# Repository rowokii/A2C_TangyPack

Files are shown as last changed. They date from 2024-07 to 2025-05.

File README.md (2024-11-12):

# A2C_TangyPack
Allows VGA and HDMI (DVI) video device to be connected to Apple IIc/IIc+ (US NTSC Machine only). 

[Laser 128 support](Laser128.md) added with Firmware V1.10

If you want to purchase one, it's avaiable from ct6502.org: [https://ct6502.org/product/tangypack/](https://ct6502.org/product/tangypack/)
</br>Please read the following [document](Compatibility.md) on compatibility before ordering. 

### WARNING!!!  Do not plug/unplug the device to/from the Apple IIc with the power on.  Damage to the device and/or to your Apple IIc can occur.  It is strongly recommended to lock the screw terminal down to prevent the device from being accidentally disconnected. 

* HDMI specification allows for hot plugging the connector.  
* Hot plugging VGA connector is not defined in the specification and there is mixed information regarding if it is safe.

# Descrpition
A2C_TangyPack plugs into the video expansion port of the Apple IIc/IIc+ and is powered from the port itself.  It is a scan doubling device that will take the 560x192 video of the Apple IIc and upscale the video to ~640x480 (720x480 @ 28.63MHz pixel rate) video resolution supported by most modern video monitors. 

## Compatibility
This became a larger topic that deserves a separate [document](Compatibility.md).   Please completely read through the document before you decide if the Tangy Pack will work for your and ordering the device

## Controls
Controls are simple.  Push the corresponding buttons to cycle through the options listed. Power on defaults are the first options of each row.  
  
  A - Toggles scanline effect On/Off  
  B - Color mode, Mono Green, Mono Amber, Mono White  
  C - Border off, Border White, Border Blue, Border Green  
  
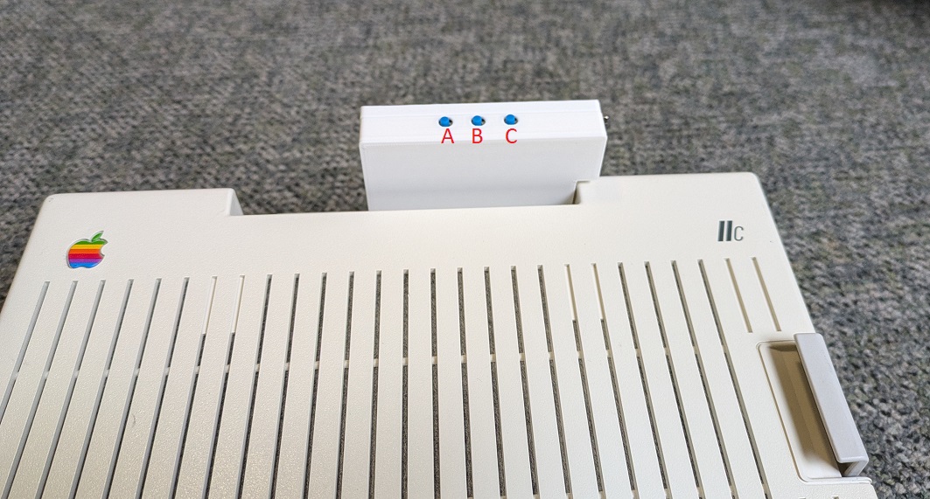
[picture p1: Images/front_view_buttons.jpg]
Front_View


# Firmware
Please read the following for the [Firmware Update](./Firmware/Firmware.md) procedure.
<br/>Firmware release notes are [here](./Firmware/Firmware_Releases.md). 

# Case STL files
If you want to print your own case, the .stl files are available in the Case STL directory.  <br/>See the [Case_STL_readme](./Case%20STL/Case_STL_readme.md) for more information.

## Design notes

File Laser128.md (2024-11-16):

# Laser 128 Support
TangyPack now works (using Firmware V1.10) on the Laser 128, with a few caveats.    <br/>Tangy Pack will auto detect when plugged into the Laser 128.

* **The original case that shipped with the Tangy Pack will not fit on the Laser 128.  Laser 128 compatible case stl is available in the Case STL folder if you have a 3D printer and you want to print your own.  Tangy Pack purchased on/after November 2024 will come with the Laser 128 compatible case**
* The case and firmware was tested with the newer style Laser 128 with  Rom V4.3 and V6.0 <br/> I do not have the old style laser 128, Laser 128EX or EX/2 so untested on these machine.  If you have these machine and the Tangy Pack works on it, please drop me a note.
* Laser 128 must have the MONO/COLOR switch in MONO setting. (Tangy Pack will display color images)
* Tangy Pack is not using the RGB signals on the Laser 128. It is using the digital serial output data and displaying the image in same way it does with the Apple IIc.  
* Laser 128 is missing the GR signal available on the Apple IIc that is used to kill the color on text modes.  This means, the Laser 128 display will always display in color unless you change the mode on the Tangy Pack itself using the "B" button.
* CREF (color reference) signal available on the Apple IIc is missing from the Laser 128.  I am internally generating the color reference from the sync video signal. Unfortunately, the color reference has different timing relationship in double high res mode and I can not detect this. <br/> So, button "A", when in Laser 128 mode, allows you to manually change the internal CREF state.  There are four valid CREF state. Each press of the button A changes the mode in the following order.
  * CREF state A - Scan line on (Default)
  * CREF state A - Scanline off
  * CREF state B - Scanline on
  * CREF state B - Scanline off
  * CREF state C - Scan line on
  * CREF state C - Scanline off
  * CREF state D - Scanline on
  * CREF state D - Scanline off
* The video timing is just a tad more out of spec compare to the Apple IIc after scan doubling.  This means some finicky monitors that work with the Tang Pack in the Apple IIc mode will not work on the Laser 128.

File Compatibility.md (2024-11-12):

# Compatibility

### A2C_TangyPack is NOT compatible with PAL at this time.

## NTSC Apple IIc/IIc+

TangyPack uses a technique called scan doubling to generate it's video signals for the VGA and HDMI/DVI compatible output.  This is method is relatively simple to implement and has minimal delay on the output image, but is tightly coupled to the source video signal timing.  Scan doubling the Apple IIc video output gets us fairly close to the 640x480 @ 60Hz video standard, but is technically out of spec.  

 **This means while many video displays will work with it, some will not.**   

 Here is a list of devices I have tested or have been reported by others to either work or not work with the Tangy Pack. [Tangy Pack Compatibility List](./Tangy%20Pack%20Compatibilty%20List%20.ods)

Please be aware some displays will scale and apply image filtering to the input images which will destroy the scanline effects and/or stretch the image from it's normal 4:3 size.

In addition, the HDMI port implementation of the Tang Nano 9K FPGA board is not strictly speaking, compliant to the HDMI/DVI standard.  This can causes several problems, which we will cover in the below section.

## Desktop Computer Monitors 
In general, these devices have the best compatibility with the HDMI/DVI and VGA outputs.  Also in general, the VGA input has better compatibility than the HDMI input.  I have a small "Security Monitor LCD" and a late 2000 LCD TV monitor that has both VGA and HDMI input.  Both LCDs works fine on the VGA input, but the HDMI input will show either blank screen or "Resolution not supported" message.

## TVs with HDCP 

These devices usually requires CEC, SCL and SDA signals on the HDMI connector to be pulled up to 5V through pull up resistors.

Tang Nano 9K does have the pull up resistors, but the 5V is not connected on the board.  

A simple $10 device called "USB Power Inserter" like this one https://www.amazon.com/dp/B08MFG27XM?ref=ppx_yo2ov_dt_b_fed_asin_title  supplies the 5V on the connector.  My LG and Samsung LCD TVs works fine with the Tangy Pack using this device. 

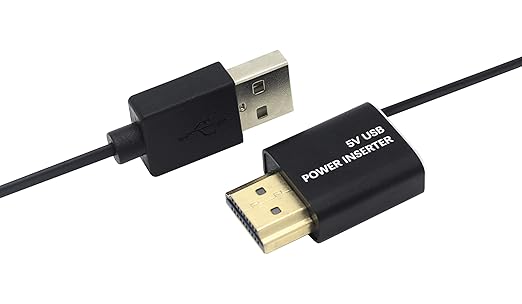
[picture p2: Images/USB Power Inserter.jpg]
Power Inserter Image
 

## HDMI Capture Cards

Tang Nano does not have the HPD(Hot Plug Detect) pin connected.  This seems to confuse the capture cards when you plug in the HDMI connector with the capture card powered up and active.  Having everything connected and then plugging in the capture card and then activating the device seems to work best for me.

Second issue is that some of the capture cards seems to be very particular about the video timing or does not support the 640x480@60 resolution.  One capture device I have will not lock to even to spec compliant 640x480@60 test signal.  

Third issue seems to be some of these devices does not like the output driver of the Tang Nano.  It causes image artifacts on the screen like shown below.

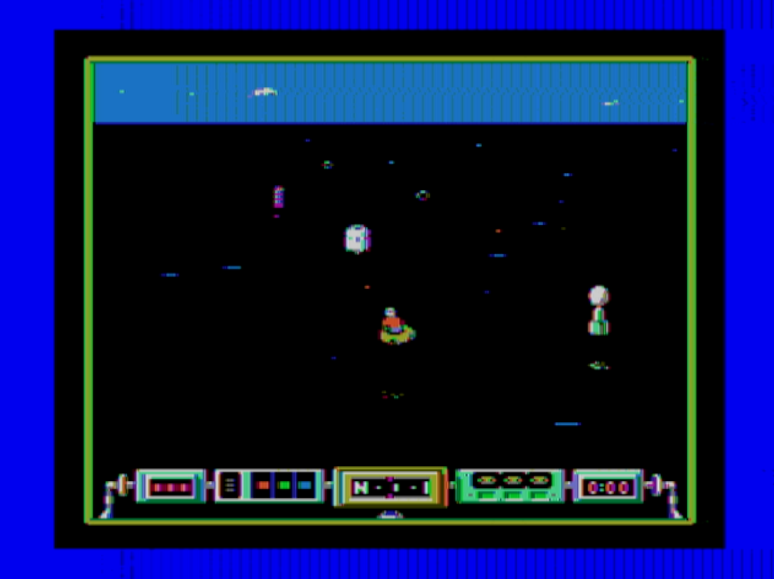
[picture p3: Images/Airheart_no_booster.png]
distorted image


Using an active HDMI signal repeater/booster device fixes the image problem. 

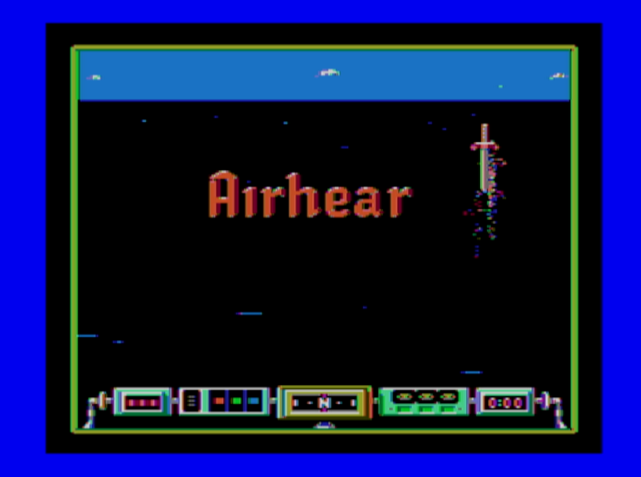
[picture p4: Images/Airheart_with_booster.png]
clean image


What you are looking for is an **active** hdmi repeater. The passive HDMI connector meant to just extend the cable will not work.  Amazon seems to have a few models from ~$20 to ~$40.  I also found a few ~$10 devices on Aliexpress that seems to work.  Here's the list of devices that I have tried.

* [Amazon Bytecc HDMI Amplifier Repeater ](https://www.amazon.com/dp/B0CRK292K6?ref=ppx_yo2ov_dt_b_fed_asin_title&th=1) ~$25 Worked
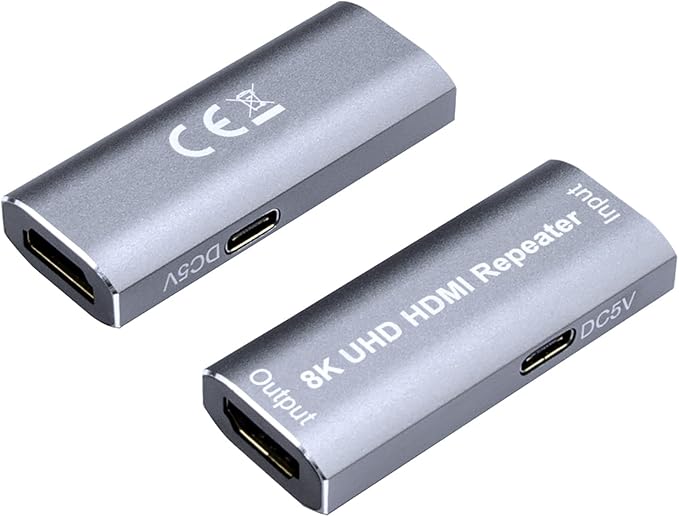
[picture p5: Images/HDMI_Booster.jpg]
HDMI Booster
<br/>
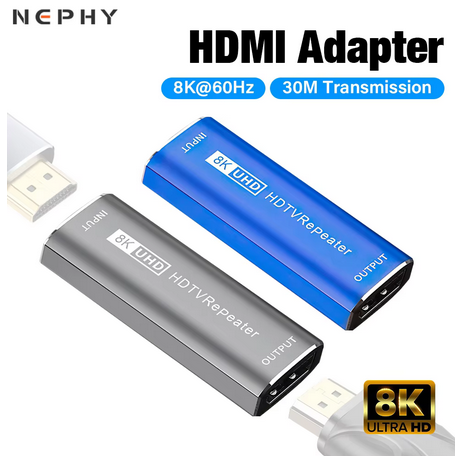
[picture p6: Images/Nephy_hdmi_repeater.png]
NEPHY Image
* [Aliexpress - 8K HDMI Signal Amplifier Booster Extender](https://www.aliexpress.us/item/3256806506866287.html) ~$8 Worked <br/>

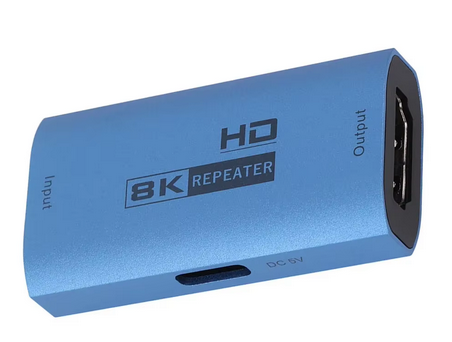
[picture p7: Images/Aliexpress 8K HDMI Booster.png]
Ali HDMI Booster
* [Aliexpress - 8K Extender Repeater](https://www.aliexpress.us/item/3256806639053743.html) ~$8 Worked <br/>
* [Aliexpress - Mini 4K*2K HDMI 2.0 Extender](https://www.aliexpress.us/item/3256804417878705.html) ~$15.  **Did NOT work** . Looses lock and blinks
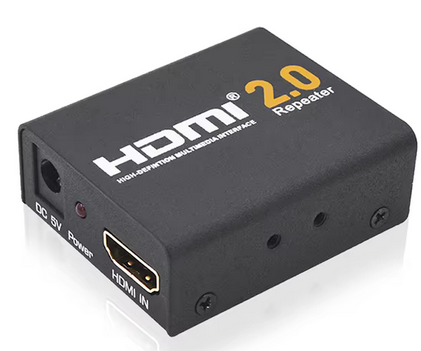
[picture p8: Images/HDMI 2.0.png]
HDMI 2.0 Booster
<br/>

Using the active HDMI booster, I was able to get two (Grey and larger black) of my test capture devices to work.  I could not get the small black HDMI to USB2 capture device to work at all.

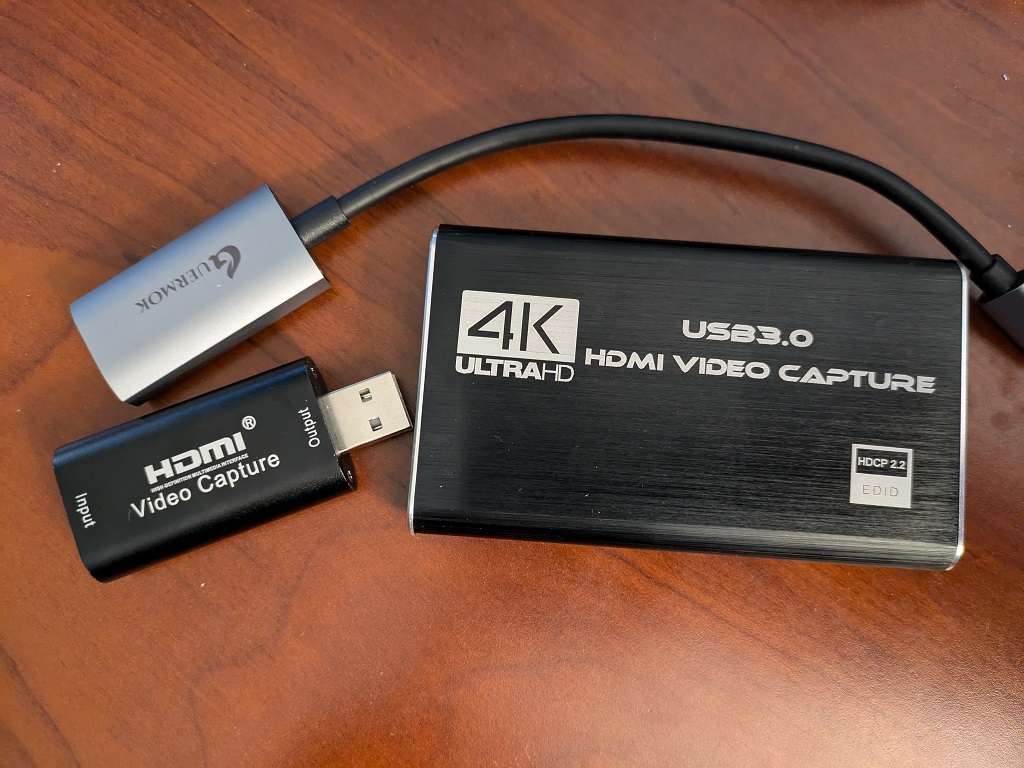
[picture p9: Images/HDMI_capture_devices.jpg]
HDMI Capture Devices


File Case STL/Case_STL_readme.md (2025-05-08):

The files for the case of the Tangy Pack is in this folder.  

The case has been designed and tested to print in ABS, but as long as you print both the front and back of the case in same material, it should be OK to print in PLA or PETG.  

PLA might be too brittle for Clips.stl so you should print it in PETG or ABS. 

Additional hardware:
  - 5 - "Voron" style heat inserts.  M3 x 5 x 4 (M3 thread, OD 5mm, length 4mm).  
  - 5 - M3 x 8mm flat head phillips head.

Print Settings used:
  - Polymaker ABS, White (Some early cases printed in Bambulab ABS, white)
  - 0.4mm Nozzle
  - 0.2mm layer
  - 0.4mm line width
  - 4 walls, 5 top and bottom layers
  - 25% Adaptive Cubic infill
  - No support needed (front case has built in support)
  - Brim is recommended for ABS (not needed for the clips.stl)

Print Files
  - Tangy_Pack_back.stl - Back of the case
  - Tangy_Pack_front_support_V2.stl - Updated case front that is compatible with Apple IIc and Laser 128.  It has built in support
  - clip.stl -clip used to hold in the tab screws

  Alternative
  - Tangy_Pack_front_support.stl - Front of the case with built in support (original Apple IIc only case)
  - Tangy_Pack_front_NO_support.stl - This is the front of the case without built in support if you want to use your own support, modify the design or use different print orientation
  - Tangy_Pack_front_NO_support_V2.stl - V2 case without support.

Extra 
  - TN9K_PCB_spacer.stl - Only used as spacer jig when assembling the PCB.

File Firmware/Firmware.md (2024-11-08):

# Firmware Update Procedure

## Taking apart the Tangy Pack

Remove the 5 M3x8mm screws using a phillips #1 screw driver from the back of the Tang Pack.  Lift off the back, including the locking screws.  

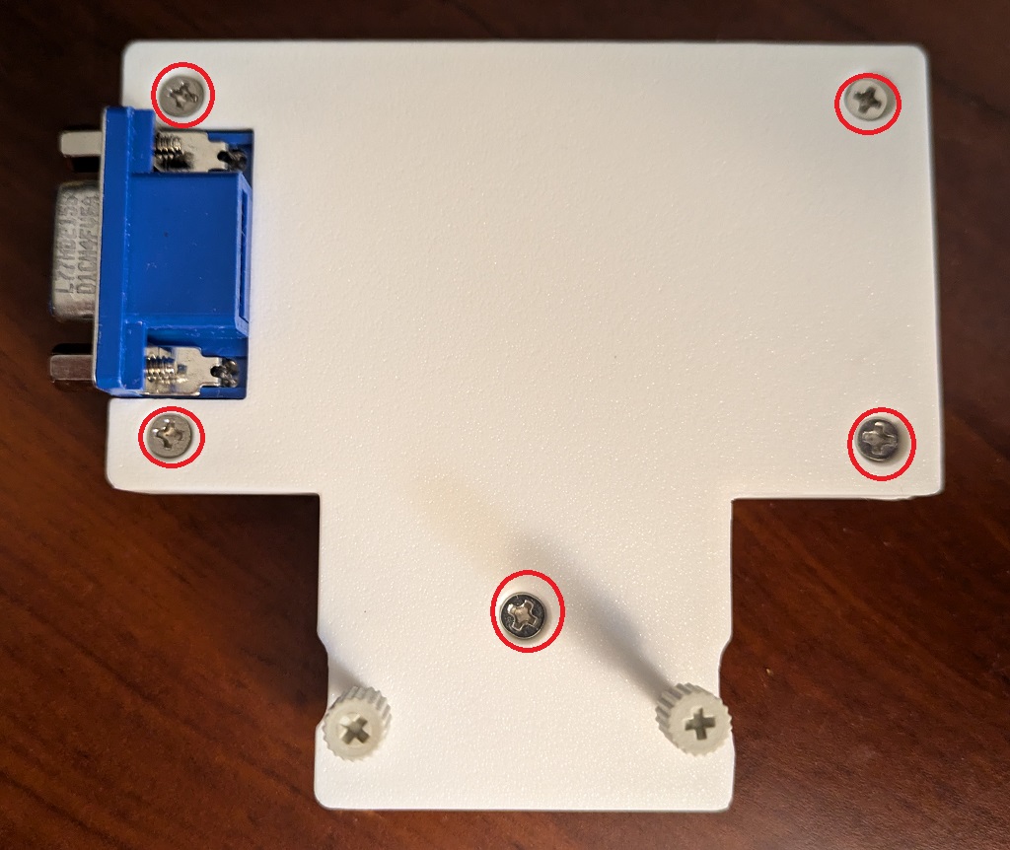
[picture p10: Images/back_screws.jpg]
Back_Screws


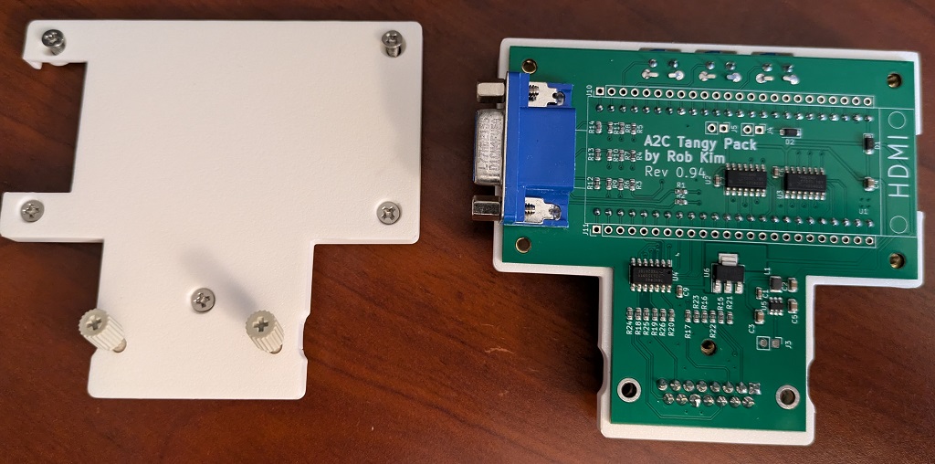
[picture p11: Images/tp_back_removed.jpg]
tp_back_removed


Once the back is removed, remove the PCB from the front case and flip it over.  There is a USB C connector under the SD card slot.  

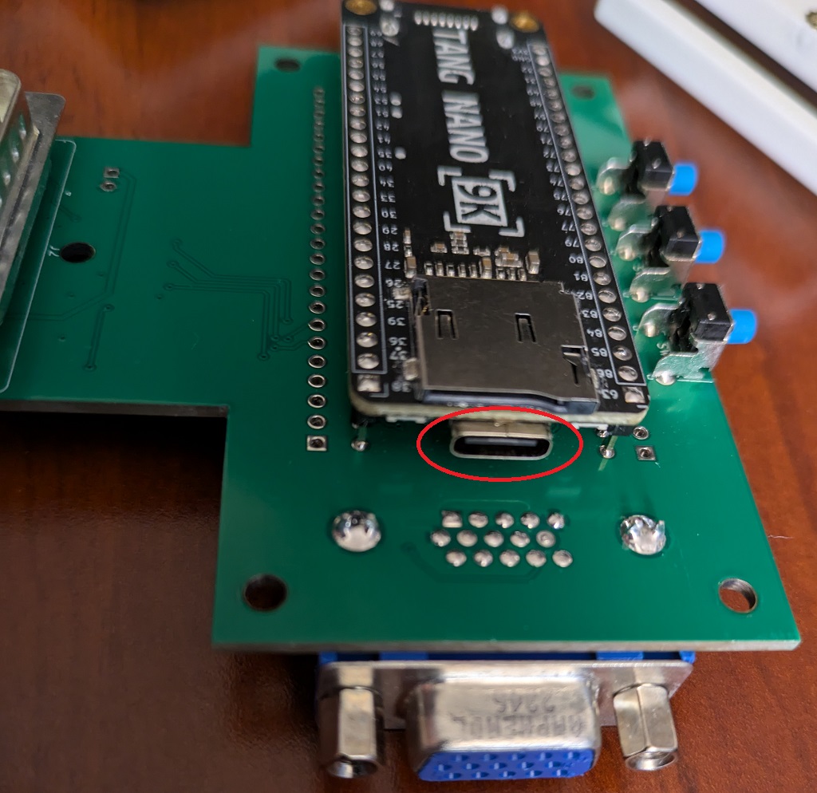
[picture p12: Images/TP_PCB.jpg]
TP_PCB


# Uploading the firmware

Once you have access to the USB C connector on the Tangy Pack, you have two options to upload the firmware file (Firmware_Name.fs).  Option 1, I feel is easier if you just want to upload the firmware.  Use option 2 if you want to get into development with Tang Nano FPGAs.

## Option 1: openFPGALoader

[openFPGALoader](https://github.com/trabucayre/openFPGALoader) is a fantastic open source software that allows you to program many FPGA boards from many manufacturers.   It works under Linux, Windows and macOS.  While the [installation guide](https://trabucayre.github.io/openFPGALoader/guide/install.html) has instructions for linux and macOS, the windows section is blank.

I was able to install and use openFPGALoader under Windows using the following [guide](https://fpga.mit.edu/6205/F22/documentation/openFPGA).  It uses [MSYS2](https://www.msys2.org/) for the actual install of the tool and command shell and [Zadig](https://zadig.akeo.ie/) for driver installation.  Only difference I ran into when following the guide was when replacing the FTDIBUS driver for WinUSB, my Tang Nano 9K device was listed as "JTAG Device" instead of "Digilent USB Device".  You need to update both interface 1 and interface 2 with WinUSB.

After you have installed the openFPGALoader, copy the firmware_name.fs file to a directory accessible from your MSYS2 command window.  Connect the Tang Nano 9K board to your computer and from the MSYS2 command window, you should be able to detect the board using the following command.

```
$ openFPGAloader --detect
No cable or board specified: using direct ft2232 interface
Jtag frequency : requested 6.00MHz   -> real 6.00MHz
index 0:
        idcode 0x100481b
        manufacturer Gowin
        family GW1N
        model  GW1N(R)-9C
        irlength 8
```

Assuming the firmware file is in the correct directory, you can use the following command to upload the new firmware

```
$  openFPGAloader -b tangnano9k -f A2C_TangyPack_V1p00.fs
write to flash
Jtag frequency : requested 6.00MHz   -> real 6.00MHz
Parse file Parse A2C_TangyPack_V1p00.fs:
Done
DONE
Jtag frequency : requested 2.50MHz   -> real 2.00MHz
erase SRAM Done
erase Flash Done
write Flash: [==================================================] 100.00%
Done
```

## Option 2: Install the Gowin EDA and Programmer

Gowin is the FPGA chip manufacturer.  They have a student version of the GOWIN EDA does not require any license to run.  It has reduced device support and feature, but the FPGA used in the Tang Nano 9K is supported

Sipeed is the manufacturer of [Tang Nano 9K](https://wiki.sipeed.com/hardware/en/tang/Tang-Nano-9K/Nano-9K.html) board used in the Tangy Pack.  They have a forked version of the Gowin programming software, that you must use to program the Tang Nano.

* [GOWIN EDA - Student Edition](https://magicjellybeanfpga.github.io/mjb/software.html)
* [Sipeed Tang Programmer](https://dl.sipeed.com/shareURL/TANG/programmer)

Once the EDA software and the programmer software has been installed, start the GOWIN EDA software.  Click on the Programmer icon.

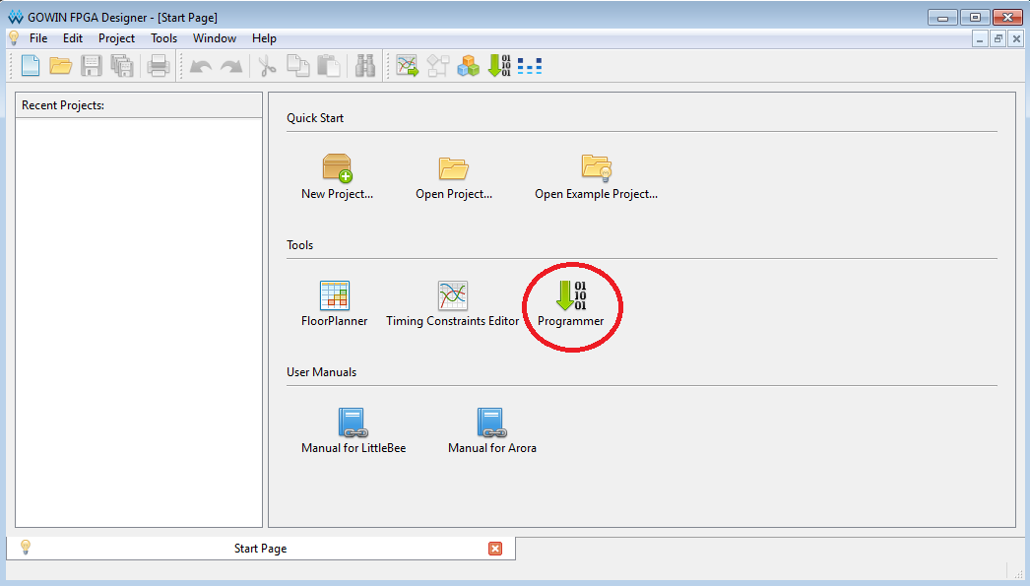
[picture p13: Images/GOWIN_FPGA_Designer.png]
GOWIN FPGA Desginer


Once the programmer software starts, connect the Tang Nano to the computer.  Click on the magnifying icon to scan for a device.  If two device shows up, select the GW1NR-9C and hit ok.

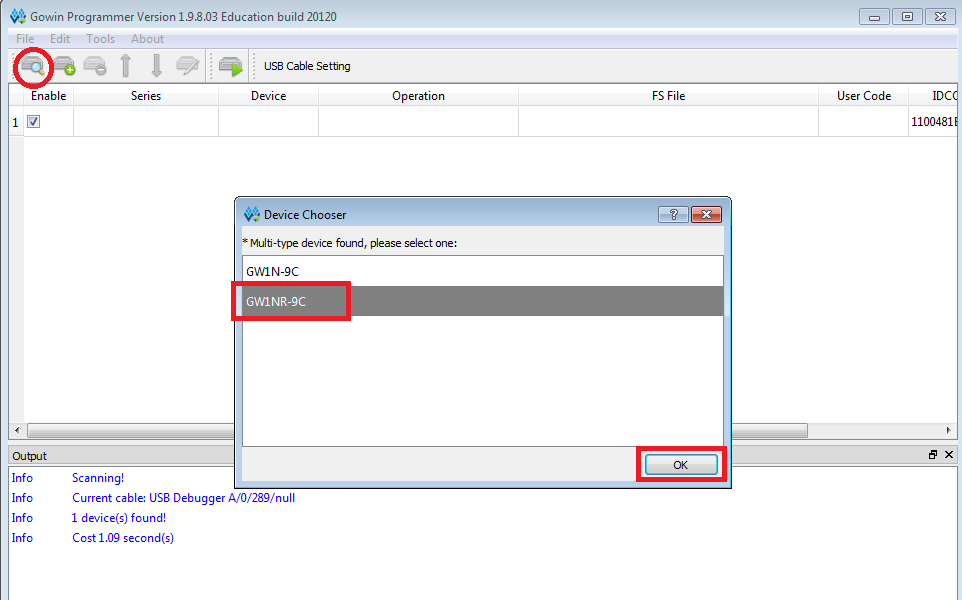
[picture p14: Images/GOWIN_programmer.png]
GOWIN Programmer


Double click on the Read Device Codes selection box.  This will bring up Device configuration window.  Select Embedded Flash Mode for Access Mode and Select embFlash Erase,Program for Operation.  

Navigate to the .fs file you want to upload for the file name and hit save

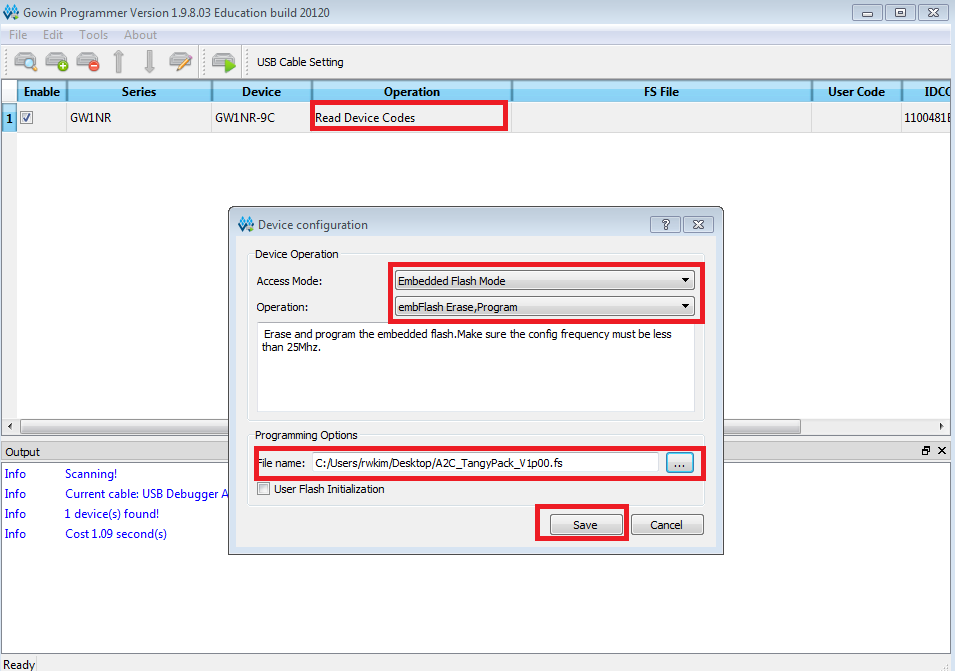
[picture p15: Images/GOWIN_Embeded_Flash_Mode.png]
GOWIN Embeded Flash


Click on the icon with green triangle to start the programming process.
You should see "Info Finished!" when the programming completes successfully.
 
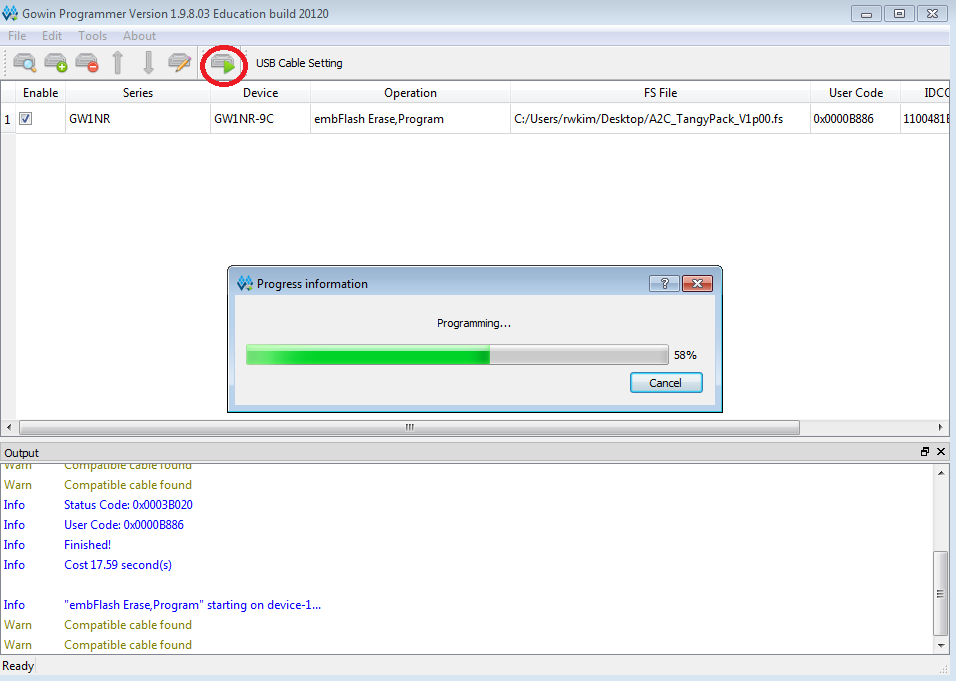
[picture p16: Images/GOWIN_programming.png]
GOWIN Programming


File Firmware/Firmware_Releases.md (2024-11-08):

# Firmware Release Notes

| Firmware Name | Description
|:---|:---|
|A2C_TangyPack_V1p00.fs | Original firmware.  Any Tangy Pack purchased before November 2024 came with this version.|
|A2C_TangPack_V1p01.fs | Fixed sync polarity on VGA output which prevented some monitors from centering the image properly.  By default, turn on the white border to help monitors that auto sync on power up.  Previously found in the Experimental section under A2C_TangyPack_V1p00_sync_invert_exp_WB.fs
|A2C_TangPack_V1p10.fs | * Laser 128 support added.  It auto-detects when plugged into Laser 128 to switch mode<br/> * Draws a thin border and displays firmware version number on lower left corner for ~10 seconds on power up.<br/> * Button response improved <br/> * The color borders are now a bit thinner with more black space around the Apple IIC/Laser 128 Images|

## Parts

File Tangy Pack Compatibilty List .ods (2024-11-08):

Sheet: Monitor
 |  |  |  | Apple IIC |  | Laser 128
Type | Make | Model | Description | HDMI | VGA | HDMI | VGA | 4/3 Mode | Comments
Monitor | Acer | EK240Y | 23.8" 1920X1080P Monitor | OK | OK | OK | OK | Yes
 | Arzopa | A1 GAMUT SLIM | 14" 1920x1080P Portable Monitor | OK | N/A | OK | N/A | Yes
 | Dell | 2007FPb | 20" 1600x1200 Monitor | OK (DVI) | OK | OK (DVI) | OK | Yes | DVI to HDMI adapter or cable needed
 | Dell | E198FPb | 19" 1280x 1024 VGA Monitor | NA | OK | NA | OK | Yes
 | Dell | S2722QC | 27" 4K HDMI Monitor | Yes | NA | ? | NA | ? | Reported working on HDMI by JL
 | EYOYO | EM14A | 14" Monitor | NO (Distorted Image) | YES | ? | ? | ? | Reported working on VGA, but distorted image on HDMI by JL
 | Haiway | SM10.1 | 10.1" 1366x768 Security Monitor | NO | OK | NO | NO | Yes | Finicky about timing. Only VGA input with Apple IIc works
 | Kenowa | HD-133 | 13.3" 1366X768 Portable Monitor | OK | NA | OK | NA | Yes
 | Sony | SDM-HS53 | 15" 1024x768 VGA Monitor | NA | OK | NA | OK | Yes

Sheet: TV
 |  |  |  | Apple IIC |  | Laser 128
Type | Make | Model | Description | HDMI | VGA | HDMI | VGA | 4/3 Mode | Comments
TV | Insignia | NS-LCD19 | 19" LCD TV | NO | Yes | NO | NO | Yes | Finicky about timing. Only VGA input with Apple IIc works
 | LG | 49LJ5500-UA | 49" LCD TV | OK (5V Required) | N/A | OK (5V Required) | N/A | Yes | Requires 5V Power Injection
 | Samsung | UN50H5203AF | 50" LCD TV | OK (5V Required) | N/A | OK (5V Required) | N/A | Yes | Requires 5V Power Injection

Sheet: Capture Devices
 |  |  |  | Apple IIC |  | Laser 128
Type | Make | Model | Description | HDMI | VGA | HDMI | VGA | 4/3 Mode | Comments
HDMI Capture | Adafruit | 4910 | USB-C to HDMI Capture Card | NO | NA | NO | NA |  | Does not lock to signal - Reported by CT
 | Audio Express | AXHDCAP | HDMI to USB 2.0 Video Capture Device | NO | NA | NO | NA |  | Does not lock, blank screen
 | Guermok | ‎GVC-HDMI-USB3-4K30 | HDMI to USB3.0(USBC) Capture Device | OK(Boost Required) | NA | OK(Boost Required) | NA | Yes | Requires Active HDMI Signal Booster.
 | Rybozen | V316B-FR | HDMI to USB3.0 Video Capture Device | OK(Boost Required) | NA | OK(Boost Required) | NA | Yes | Requires Active HDMI Signal Booster.

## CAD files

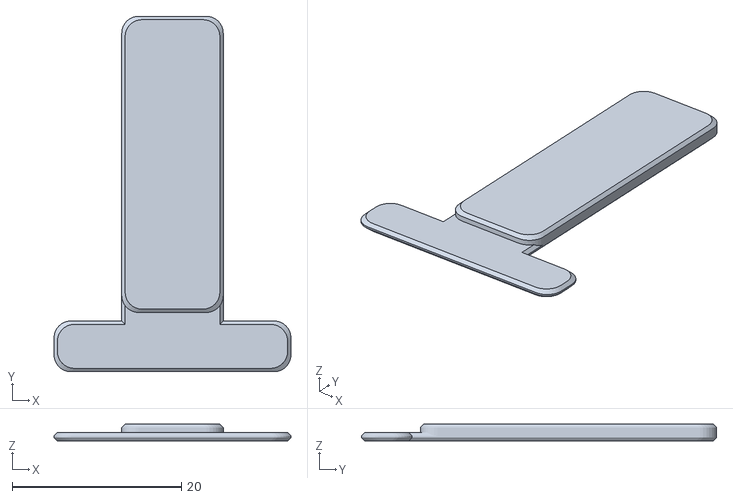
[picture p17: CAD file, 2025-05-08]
Case STL/TN9K_PCB_spacer.stl
28.0 x 42.0 x 2.00

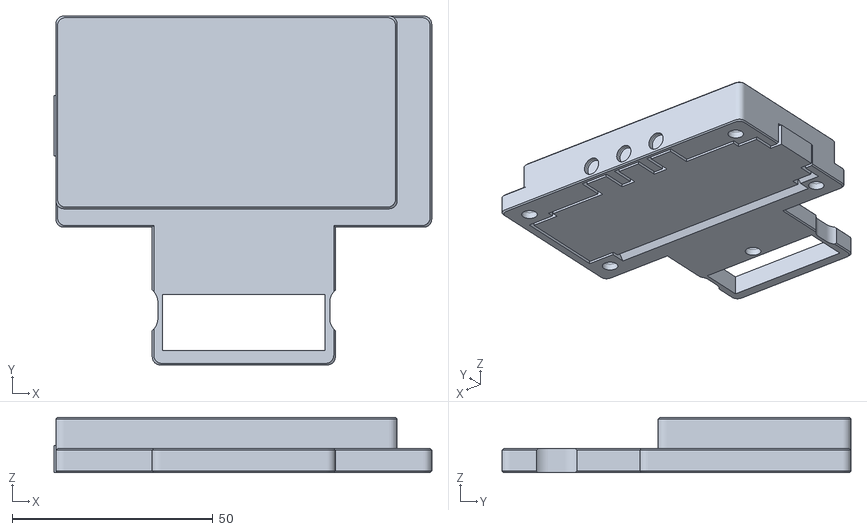
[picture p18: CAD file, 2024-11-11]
Case STL/Tangy_Pack_front_support_V2.stl
94.0 x 86.9 x 13.8

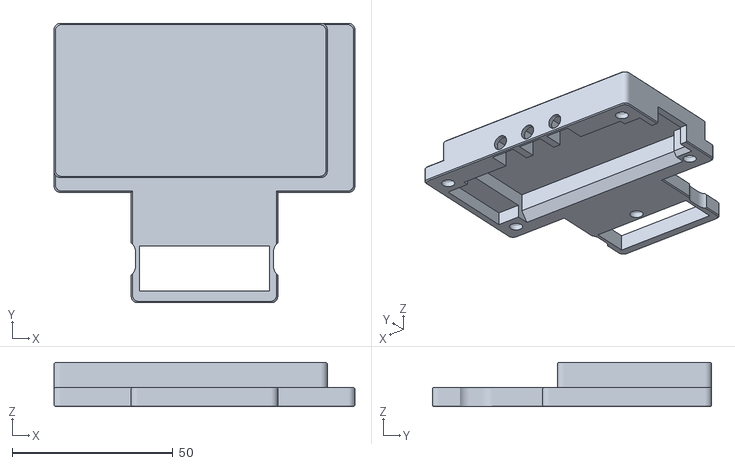
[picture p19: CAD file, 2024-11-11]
Case STL/Tangy_Pack_front_NO_support_V2.stl
93.6 x 86.9 x 13.8

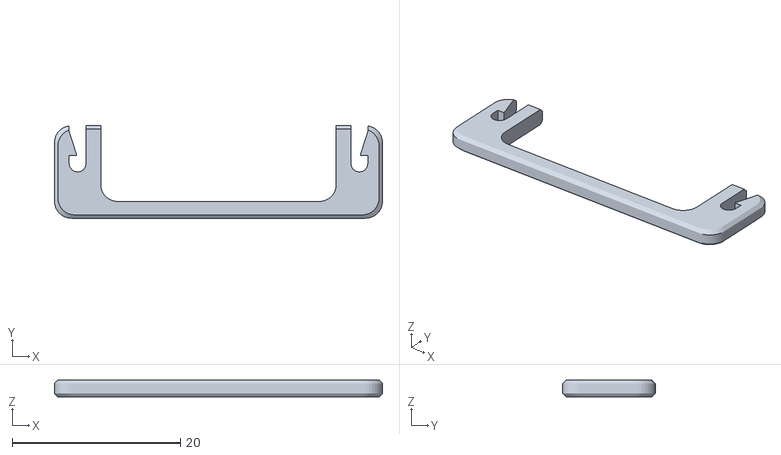
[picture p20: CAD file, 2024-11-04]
Case STL/clip.stl
39.0 x 11.0 x 2.00

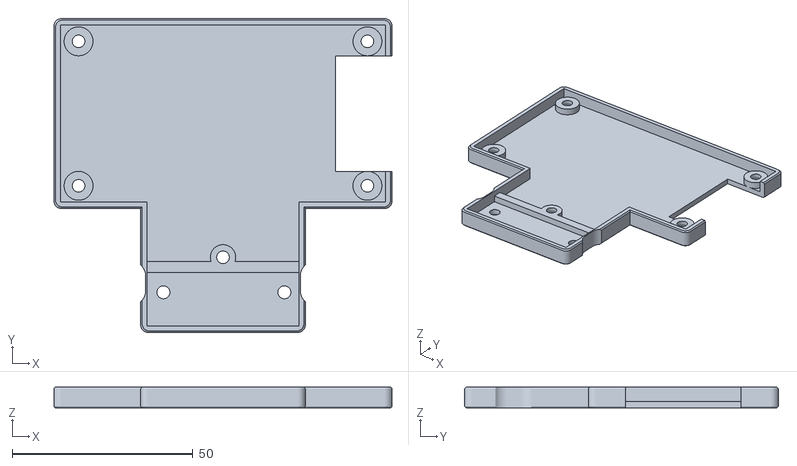
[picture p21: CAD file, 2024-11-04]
Case STL/Tangy_Pack_back.stl
93.6 x 86.9 x 5.80

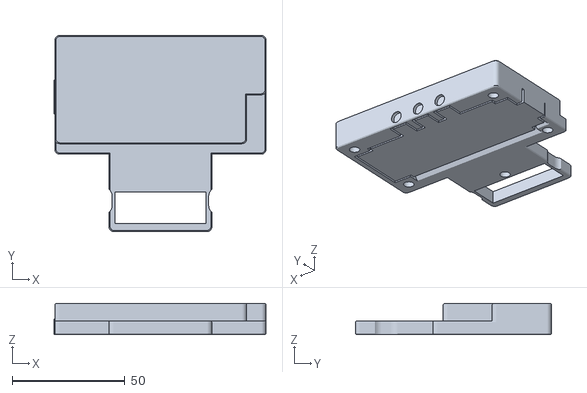
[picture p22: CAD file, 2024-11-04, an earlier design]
Case STL/Tangy_Pack_front_support.stl
94.0 x 86.9 x 13.8

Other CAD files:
Case STL/Tangy_Pack_front_NO_support.stl

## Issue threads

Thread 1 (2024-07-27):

Feature request: Support mixed color/B&W DHGR mode

bhtooefr, 2024-07-27:
Video7 and Le Chat Mauve sold adapters for the //c that provided an RGB output, and added a new video mode, a so-called "mix mode", using the unused high bit of every video byte to switch between color and monochrome.

As far as I'm aware, no modern video adapters for the //c support this mode.

Documentation from adapter manufacturers:
Video7 Color Enhancer IIc (for CGA-style monitors): https://mirrors.apple2.org.za/Apple%20II%20Documentation%20Project/Peripherals/Video/Video-7%20Color%20Enhancer%20IIc/Manuals/Video-7%20Color%20Enhancer%20IIc%20-%20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
Video7 RGB Interface //c (for analog RGB monitors): https://mirrors.apple2.org.za/ftp.apple.asimov.net/documentation/hardware/video/Video7%20for%20Apple%20IIc%20Manual.pdf

A couple of //e interfaces' documentation:
Video7 64K RGB Interface //e (may have some programming info for the Video7 implementation, but also describes some modes not available on the //c - this adapter was also rebranded by Apple as the official RGB card for the //e in the US): https://mirrors.apple2.org.za/ftp.apple.asimov.net/documentation/hardware/video/Video-7%20RGB-SL7.pdf
Le Chat Mauve Feline (//e card that is compatible with the //c adapter): https://ftp.apple.asimov.net/documentation/hardware/video/Le%20chat%20mauve%20Feline%20manuel%20OCR.pdf

An example of mix mode on a NTSC //c, using a Le Chat Mauve IIc RVB Peritel adapter (intended for 50 Hz //cs, but worked perfectly on my 60 Hz), with a generic SCART to HDMI adapter, into a HDMI to VGA adapter to go into a 21" CRT:
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

I'm unsure how these adapters actually detected selecting mix mode, or how they detected the high bit on the //c video port, but it's clear that they're doing it _somehow_.

rowokii, 2024-07-27:
Do you have any software that generates the mixed mode image?  Maybe I can poke at the video port and see what's coming out when it's using this mode.

bhtooefr, 2024-07-27:
http://mirrors.apple2.org.za/Apple%20II%20Documentation%20Project/Interface%20Cards/Apple%20IIe/Apple%20IIe%20Extended%2080%20Column%20RGB%20Card/Disk%20Images/ has some demo disks for the Video7 //e card.

From that card's manual:

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

http://boutillon.free.fr/Underground/Anim_Et_Graph/Extasie_Chat_Mauve/Dsp_Img/Disks/Dsp_Img.dsk.gz is targeted towards the Le Chat Mauve Feline and IIc adapter.

I'd also look at https://github.com/AppleWin/AppleWin/issues/764 as it discusses some differences between the implementations.

rowokii, 2024-07-28:
OK, so my code tries to imitate the artifact coloring effect of the NTSC monitor/TV vs as far as I can tell, the RGB interface does a simple straight up map color to bit patterns.  So, in theory, it should be possible to map signal to match the RGB output, but in practice it might be a pain to try to figure out the actually mapping.   I'm going to have to back burner this for a bit while I work on couple of higher priority feature sets I have in mind, but I definitely want to explore this some more.

My device displays pretty much what I see in Applewin when set to color monitor/TV mode.

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

What's strange is on the DHR.COLORS code, my output looks completely borked.

My Apple IIC
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

AppleWin display of same demo
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

If you look at the  Purple for example, my computer looks like it's completely missing the "P", "r", and "l".   ????

bhtooefr, 2024-07-28:
That looks to me like the mode switching ended up in hires, not DHR?

In any case, I *think* an acceptable behavior would be to, essentially, disable color burst/NTSC color emulation on a per byte/7 pixel basis instead of a per frame basis? Probably not exactly accurate, but close enough. (You'll also run into, Le Chat Mauve colors are not quite the same as NTSC colors, and Video-7 colors range from "pretty close" to "literally mapping Apple II colors to CGA RGBI colors". I think ignoring *those* details would honestly be fine.)

Also, implementing the BW560 mode that disables color emulation per-frame automatically would be nice, too - some stuff like MouseDesk actually uses that if it's available. Might be easier to implement CO140 and BW560 first, as it's effectively just switching functionality that already exists on your adapter from the computer side rather than the buttons on it, then implement mix mode later.

rowokii, 2024-07-29:
So, it looks like the DHR demo is not compatible with IIc.  It works fine in a IIe, but every IIc I have tried(rom 255, 0, 4 and IIc+), the initial drawing is fine, but it flicks at the end I get the distorted image.

Looking at the signal available at the IIc video expansion port, I see a signal called "VIDD7 - From 74LS374. Video Latch.  Causes half-dot shift high"  This sure sounds like the 7th bit you are referring too.   Sounds a lot like the name of the interface Video-7 too!

In any case, the bad news is that I will not be able to support this mode on the current hardware if I need to look at VIDD7 signal.
1 - TEXT, 4 - SEGB, 6 - LDPS, 9 - PRAS,  & 14 - VIDD7 are signals that are not connected to the FPGA.  I would have to add another level shift buffer chip.

rowokii, 2024-07-31:
Right.  Tangy Pack actually doesn't know what video mode the Apple IIc is in.  It just takes the pixel data and the color reference signal to map the artifact color and looks at the GR signal to see if it should suppress the color for the text screen (as well as in monochrome modes, of course).  So, for normal video modes, I don't need to look at VIDD7.  I think to get the mono in DHR mode, I will have to observe TEXT and GR signal (TEXT is inverse of GR signal, except when in DHR mode) and once I know we are in DHR, look at VIDD7 to change to mono.   So, I think it should be possible to support this, but once again, not with current hardware.  I should try to prototype this once have some time...

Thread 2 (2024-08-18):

Does this work with the Laser 128?

cbmeeks, 2024-08-18:
I have both versions of the Laser 128.  Do you know if they would work with them?

Also, on a different note, are you the same guy that designed the internal Mockingboard clone for the IIc?

Thanks!

rowokii, 2024-08-20:
Right now, it does not work with the Laser 128.   I might be able to get it to work with a Laser 128 for monochrome mode if I remap the CSYNC signal, but it is missing the CREF signal I need to generate color images.   I will explore this a bit more once I ship out the current batch of devices.

cbmeeks, 2024-08-20:
Ah, sorry.  I bought the Mockingboard clone from him many years ago and couldn't remember his name.

Thanks.

rowokii, 2024-11-08:
Hi,  Just FYI... Laser 128 support has been added with Firmware V1.10.
https://github.com/rowokii/A2C_TangyPack/blob/main/Laser128.md

Closed 2024-08-20.

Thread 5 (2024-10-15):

HDMI does not work, VGA is shifted too much to use

dillera, 2024-10-15:
Just got one and HDMI doesn't work on any monitor I have, used the VGA w/ a VGA to HDMI upscaler and that works but image is shifted to the left too much to be useable.

Any chance there will be controls to shift the image placement?

Video:
https://www.facebook.com/100001338738932/videos/2092824124447787/

rowokii, 2024-10-15:
Hi Andrew,

Sorry to hear about your problems with the HDMI output.   The video output is not standard resolution and some monitors and especially capture cards seems to be very particular about the signaling.  This is definitely something I want to try to improve, but I have not had much time work on it yet.

Regarding centering the image.  Can you try to turn on the border right away after you turn on the device.  Or, can you re-trigger your capture card's auto sync?  The image from the Tangy Pack is centered, but the image does not take up the full screen.  By the time you turn on the border, your device has already decided on how big the image is and shifting it.

dillera, 2024-10-15:
I've looked for an auto-sync but I don't think there is one. I've tried to turn on the boarder as soon as the IIC powers on but that does not seem to make much of a difference.

rowokii, 2024-10-16:
Well, if you are willing to try updating the firmware, I can upload a new firmware that default starts with the border turned on.

Also, regarding the slowness of the device, it's something else in the video signal chain that is introducing the lag.  Tangy Pack is scan doubling the image coming from the Apple IIc, which means it has something in the order of <200uS of delay between the composite video output and VGA output.  You should not be able to see that difference.

rowokii, 2024-10-16:
Under the firmware folder:

 A2C_TangyPack_V1p00_wb.fs

This is the firmware that has the white border turned on my default

rowokii, 2024-10-18:
I had another idea about why the image could be shifting.  I removed the above firmware image and put two new firmware in the Experimental folder.  If so inclined, can you try to flash the firmware with _WB.fs ending to see if this fixes your image shifting problem?

dillera, 2024-10-18:
Absolutely, thanks for thinking about this and spending some time on it. I'll try and update this thread today.

dillera, 2024-10-18:
Success!
$ openFPGAloader -b tangnano9k -f ~/Downloads/A2C_TangyPack_V1p00_sync_invert_exp_WB.fs
Using that does center it now at least VGA->VGA/HDMI Upscaler.

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

dillera, 2024-10-18:
There is that one white vertical strip all the way on the right of the image that is not part of the boarder and does not go away. Other than that it seems to work nicely and I can remove the border via the button, using FujiNet to boot an image and the Tangy does not reset (it stays centered).
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

rowokii, 2024-10-18:
OK, progress...

Hum... I know I overscaned the image horizontally a bit because Apple II annoyingly shift the image horizontally depending on display mode.  I thought the amount I overscanned was benign since  most of the software I tested had black in the overscan area, but I guess not.

I think you mentioned this is FujiNet.   I don't have FujiNet so I'm very ignorant of how it works, but is it possible to run the software without having the FujiNet device?  I just need the software to run enough to have a display output.

dillera, 2024-10-18:
Oh yes, FujiNet just loads disk images, you don't need FujiNet and it in no way interferes with this- it's just the way i can load an application.

Speaking of that where are the image demo utils you run in your video? The ones that show the color bars etc?

Where as in where can I download them and run them on my iic?

rowokii, 2024-10-19:
OK.  Two new firmwares in the Experimental folder.   The ones with hov_exp.fs and hov_exp_WB.fs endings.  These removes the horizontal overscans areas from displaying.   _WB.fs is the one that has the default white border like last time.

Regarding the image demos...  it's just some basic software I wrote to exercise various display modes and colors.    Uploaded under /Software folder.  It's a DOS 3.3 dsk image.

dillera, 2024-10-19:
Ok, the overscan lines are gone! I will test this further- and thanks again for sorting this out.
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

dillera, 2024-10-21:
This works nicely- hopefully you can get HDMI going on some capture devices!

Closed 2024-10-21.

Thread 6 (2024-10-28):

A2C_TangyPack & COLOR BARS

JDW1, 2024-10-28:
Rob,

I sent you an email yesterday, but it might have ended up on your SPAM filter.  I know it's out of place to post it here, but I have no other way to reach you.

I watched your Kansas Fest 2024 presentation about the Apple IIc Tangy Pack, and I noticed you used some interesting COLOR BARS at 12:27 in this video:

https://youtu.be/Xh7fbzj6SgQ?si=3Ifv300H1Nu9JLuq&t=747

Would you mind sharing a download URL for the disk image that generates those color bars?

Thanks!

rowokii, 2024-10-28:
Hi James,

It's just a few basic programs I wrote when I was testing to display different color images.   Dos 3.3 dsk image is here:

[https://github.com/rowokii/A2C_TangyPack/blob/main/Software/A2_Graphics.dsk](https://github.com/rowokii/A2C_TangyPack/blob/main/Software/A2_Graphics.dsk)

Cheers!

JDW1, 2024-10-29:
Hi Rob,

I wish to humbly thank you for your kindness in sharing the *.dsk image.

I tested it just now in [Virtual II](https://www.virtualii.com) and found a bug regarding menu choices C & E, both of which pertain to **HGR**:

###  CHOICE "C":
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

### Emulated IIc:
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

### Emulated IIe:
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

### CHOICE "E":
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

### No "Illegal QTY" error, but I suspect this display is not what you intended:
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

rowokii, 2024-10-29:
Actually, I misnamed those files.  It's not running HGR modes but Double Low Res (DGR?) modes on those.

It works fine on an actual Apple IIc/IIc+.  I get the same errors on Laser 128 and Applewin emulating enhanced IIe.

Quick google search shows this post:
https://retrocomputing.stackexchange.com/questions/384/what-are-the-differences-between-the-versions-of-applesoft-basic

Under Apple IIc/ IIc Plus
    "The lo-res graphics commands (GR, HLIN, VLIN, PLOT, and SCRN) work with double lo-res"

So, the syntax error is because HLIN value of 79 is not valid in the previous version of Applesoft.  I guess most emulators emulates IIe, so this doesn't work...

IIc gets no love!  😀

JDW1, 2024-10-29:
Thanks, I plan to test it on my real IIc (not plus) this evening after work.  I appreciate the info!

JDW1, 2024-10-29:
Rob, I made this video and shared it on FaceBook in the Apple II group so other people will more easily be able to find it.

https://youtu.be/cFw3JKDPhRs?si=sV8AN5Iqma69Ogw5

Thanks again for kindly making it available!

Closed 2024-10-28.

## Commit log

2024-10-16 Create A2C_TangyPack_V1p00_wb.fs
    1.00 firmware with white boarder default
2024-11-04 Upload the STLs for case
    [Tangy_Pack_back.stl, Tangy_Pack_front_NO_support.stl, Tangy_Pack_front_support.stl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]
2024-11-08 V1.10 Firmware and updated info on compatibility
    [Tangy Pack Compatibilty List .ods]
2024-11-11 Updated Laser 128 compatible case
    STL added and info updated
    [Tangy_Pack_front_NO_support_V2.stl, Tangy_Pack_front_support_V2.stl]
2024-11-16 updated note regarding laser 128 case style
2025-05-08 Added PCB spacer stl
    [TN9K_PCB_spacer.stl]
2025-07-18 Uploaded case STL that does not need heat insert
